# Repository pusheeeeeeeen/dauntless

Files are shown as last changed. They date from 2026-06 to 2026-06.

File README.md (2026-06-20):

# LiHv battery charger V1+V2
LiHv battery charger capable of charging LiHv batteries up to 4.35v, custom 3d designed case for 3d printing and an on-off switch. V1 is the simplest module, just to be available for cheaper and easier production of 4.35v LiHv chargers. V2 is equipped with a buzzer, OLED display, and XIAO RP2040 module to track battery percentage, and to alert the user when the battery is done charging. 

## V1: Mr. Barebones
### 3D rendering
Screenshot 2026-06-17 at 2 48 51 PM

### Schematic
Screenshot 2026-06-15 at 2 58 24 PM

### PCB Layout
Screenshot 2026-06-19 at 8 40 17 PM

## V2: The Upgrade
### 3D rendering
Screenshot 2026-06-19 at 8 35 19 PM

### Schematic
Screenshot 2026-06-18 at 3 53 26 PM

### PCB Layout
Screenshot 2026-06-19 at 8 37 02 PM

## BOM:
https://docs.google.com/spreadsheets/d/1y4eYakeZhQ_Du6QSC2gYvQQuMS255J4ouP4txh3QHf0/edit?gid=0#gid=0

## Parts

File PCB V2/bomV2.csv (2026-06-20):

Reference | Value | Footprint | Datasheet | Qty | DNP | Exclude from BOM | Exclude from Board
BZ1 | Buzzer | Buzzer_Beeper:Buzzer_D14mm_H7mm_P10mm | ~ | 1
C2,C3 | 10uF | Capacitor_THT:CP_Radial_D5.0mm_P2.50mm | ~ | 2
D1,D2 | LED | LED_SMD:LED_0805_2012Metric_Pad1.15x1.40mm_HandSolder | ~ | 2
J1 | "OLED Display" | Connector_PinSocket_2.54mm:PinSocket_1x04_P2.54mm_Vertical | ~ | 1
J2,J3 | Conn_01x01 | Connector_PinSocket_2.54mm:PinSocket_1x01_P2.54mm_Vertical | ~ | 2
R3 | 2.2k | Resistor_SMD:R_0805_2012Metric_Pad1.20x1.40mm_HandSolder | ~ | 1
R4,R5 | 1k | Resistor_SMD:R_0805_2012Metric_Pad1.20x1.40mm_HandSolder | ~ | 2
R6,R8 | 0.2 | Resistor_SMD:R_0805_2012Metric_Pad1.20x1.40mm_HandSolder | ~ | 2
R7 | 10k | Resistor_SMD:R_0805_2012Metric_Pad1.20x1.40mm_HandSolder | ~ | 1
SW1 | SW_SPST | Button_Switch_THT:SW_Slide_SPDT_Straight_CK_OS102011MS2Q | ~ | 1
U1 | TP4056X-435-ESOP8 | Package_SO:SOIC-8-1EP_3.9x4.9mm_P1.27mm_EP2.62x3.51mm_ThermalVias | https://www.lcsc.com/datasheet/lcsc_datasheet_2410121619_TOPPOWER-Nanjing-Extension-Microelectronics-TP4056-42-ESOP8_C16581.pdf | 1
U2 | XIAO-RP2040-SMD | SeeedStudioLibrary:XIAO-RP2040-SMD |  | 1

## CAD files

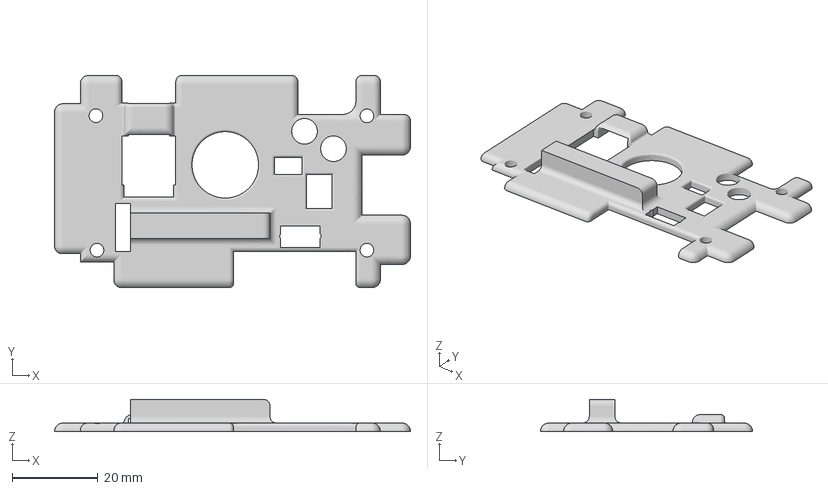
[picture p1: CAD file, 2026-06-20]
PCB V2/LiHvbatterychargerV2enclosuretopcover.3mf
83.0 x 49.5 x 7.51 mm

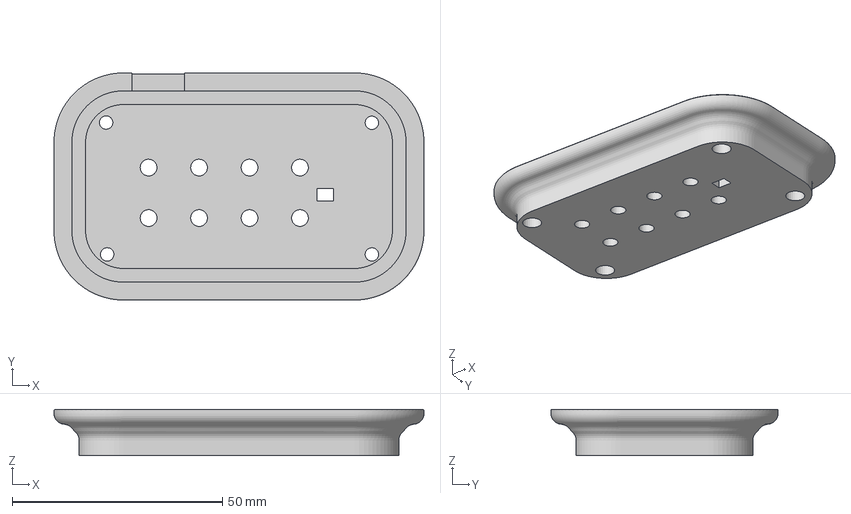
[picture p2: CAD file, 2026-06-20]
PCB V2/LiHvbatterychargerV2enclosurebottom.3mf
88.0 x 54.0 x 11.0 mm

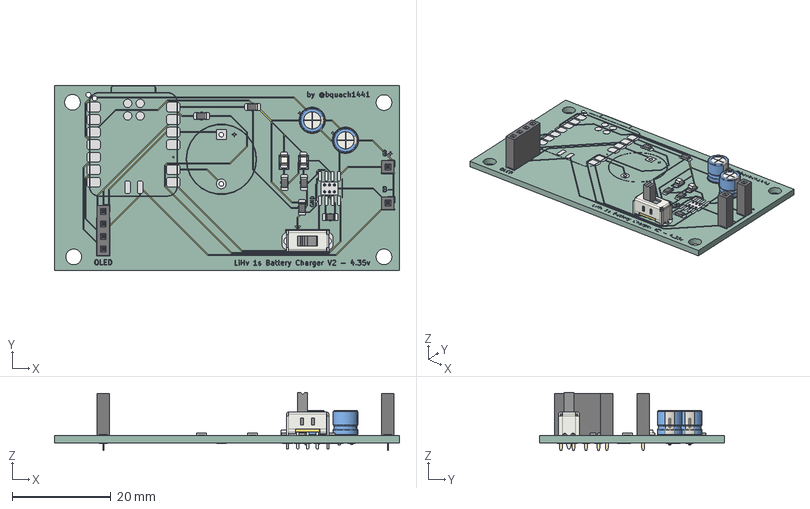
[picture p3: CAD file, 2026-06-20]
PCB V2/LiHvbatterychargerv3.step
70.0 x 37.5 x 11.8 mm
PinSocket_1x01_P2.54mm_Vertical x 2
PinSocket_1x04_P2.54mm_Vertical
CP_Radial_D5.0mm_P2.50mm x 2
R_0805_2012Metric x 6
LED_0805_2012Metric x 2
SW_Slide_SPDT_Straight_CK_OS102011MS2Q
LiHvbatterychargerv3_copper
LiHvbatterychargerv3_pad
LiHvbatterychargerv3_silkscreen
LiHvbatterychargerv3_PCB

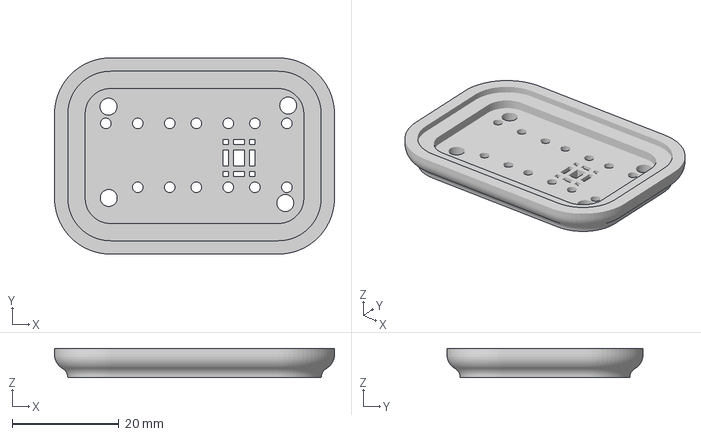
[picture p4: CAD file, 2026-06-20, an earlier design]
PCB V1/LiHvbatterychargerV1bottomenclosure.3mf
52.6 x 36.8 x 5.50 mm

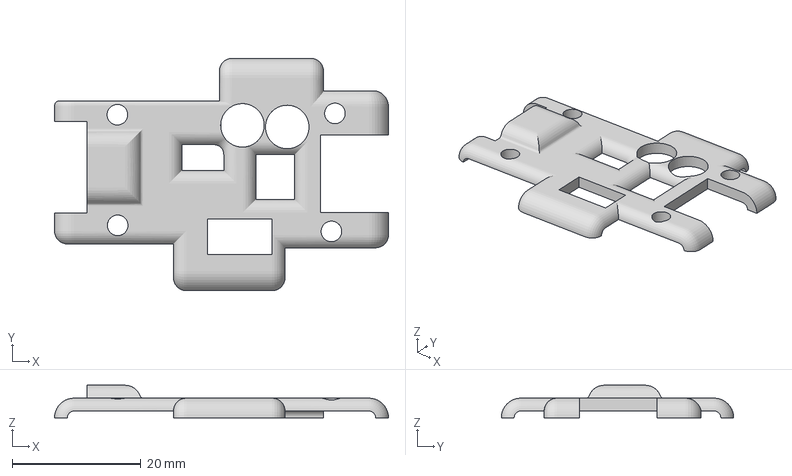
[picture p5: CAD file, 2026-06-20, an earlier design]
PCB V1/LiHvbatterychargerV1enclosuretopcover.3mf
51.8 x 36.1 x 5.06 mm

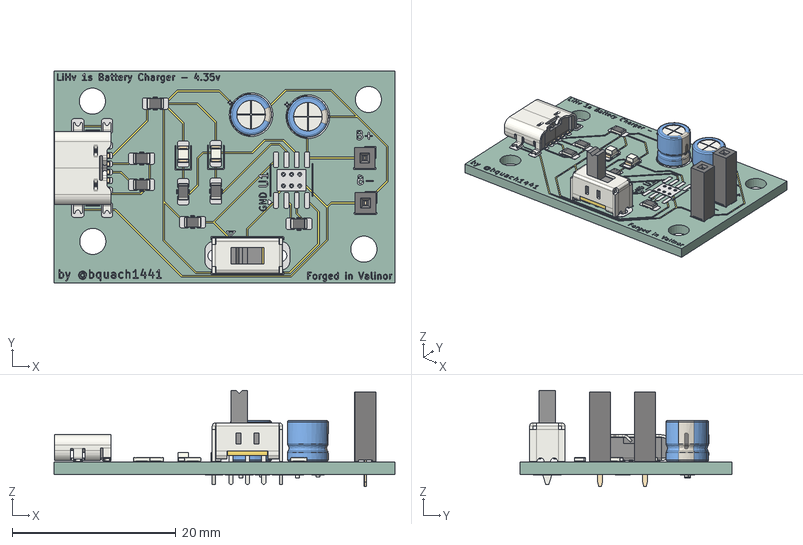
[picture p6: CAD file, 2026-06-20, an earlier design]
PCB V1/LiHvbatterychargerv2.step
41.7 x 25.9 x 11.8 mm
R_0805_2012Metric x 7
CP_Radial_D5.0mm_P2.50mm x 2
LED_0805_2012Metric x 2
PinSocket_1x01_P2.54mm_Vertical x 2
USB_C_Receptacle_GCT_USB4135-GF-A_6P_TopMnt_Horizontal
SW_Slide_SPDT_Straight_CK_OS102011MS2Q
LiHvbatterychargerv2_copper
LiHvbatterychargerv2_pad
LiHvbatterychargerv2_silkscreen
LiHvbatterychargerv2_PCB

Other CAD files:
PCB V1/LiHvbatterychargerv2enclosure.f3z

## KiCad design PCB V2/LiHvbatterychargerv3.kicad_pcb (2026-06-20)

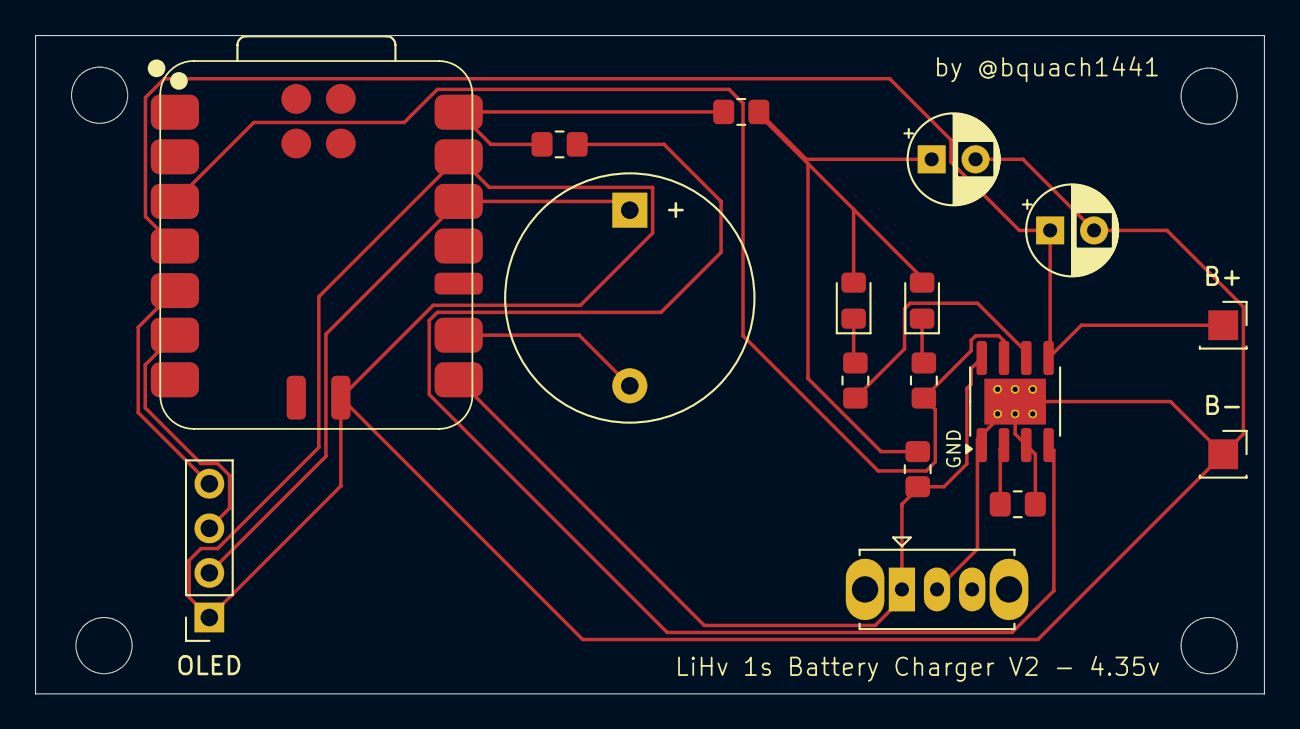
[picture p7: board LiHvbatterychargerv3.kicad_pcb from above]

Board: 2 copper layers, 70.0 x 37.5 mm, 17 parts (0 on the bottom side), 15 nets.

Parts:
B+: Conn_01x01; PinSocket_1x01_P2.54mm_Vertical
B-: Conn_01x01; PinSocket_1x01_P2.54mm_Vertical
BZ1: Buzzer; Buzzer_D14mm_H7mm_P10mm
C2, C3: 10uF; CP_Radial_D5.0mm_P2.50mm
D1, D2: LED; LED_0805_2012Metric_Pad1.15x1.40mm_HandSolder
OLED: "OLED Display"; PinSocket_1x04_P2.54mm_Vertical
R3: 2.2k; R_0805_2012Metric_Pad1.20x1.40mm_HandSolder
R4, R5: 1k; R_0805_2012Metric_Pad1.20x1.40mm_HandSolder
R6, R8: 0.2; R_0805_2012Metric_Pad1.20x1.40mm_HandSolder
R7: 10k; R_0805_2012Metric_Pad1.20x1.40mm_HandSolder
SW1: SW_SPST; SW_Slide_SPDT_Straight_CK_OS102011MS2Q
U1: TP4056X-42-ESOP8; SOIC-8-1EP_3.9x4.9mm_P1.27mm_EP2.62x3.51mm_ThermalVias
U2: XIAO-RP2040-SMD

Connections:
GND: B-.1, C2.2, C3.2, OLED.1, R3.1, SW1.2 (B), U1.1 (TEMP), U1.3 (GND), U1.9 (EPAD), U2.13 (GND), U2.33 (GND)
unnamed: BZ1.1 (+), OLED.2, U2.12 (3V3)
unnamed: BZ1.2 (-), U2.9 (P2_D8_SCK)
unnamed: C2.1, D1.2 (A), D2.2 (A), R6.1, R7.2
unnamed: D1.1 (K), R5.2
unnamed: D2.1 (K), R4.2
unnamed: OLED.3, U2.6 (P7_SCL_D5)
unnamed: OLED.4, U2.5 (P6_SDA_D4)
unnamed: B+.1, C3.1, U1.5 (BAT), U2.4 (P29_A3_D3)
unnamed: R7.1, SW1.1 (A), U1.8 (CE), U2.8 (P1_D7_RX)
unnamed: R3.2, U1.2 (PROG)
unnamed: R8.1, U1.4 (V_{CC})
unnamed: R5.1, U1.7 (~CHRG), U2.3 (P28_A2_D2)
unnamed: R4.1, U1.6 (~STDBY)
unnamed: R6.2, R8.2, U2.14 (VBUS)

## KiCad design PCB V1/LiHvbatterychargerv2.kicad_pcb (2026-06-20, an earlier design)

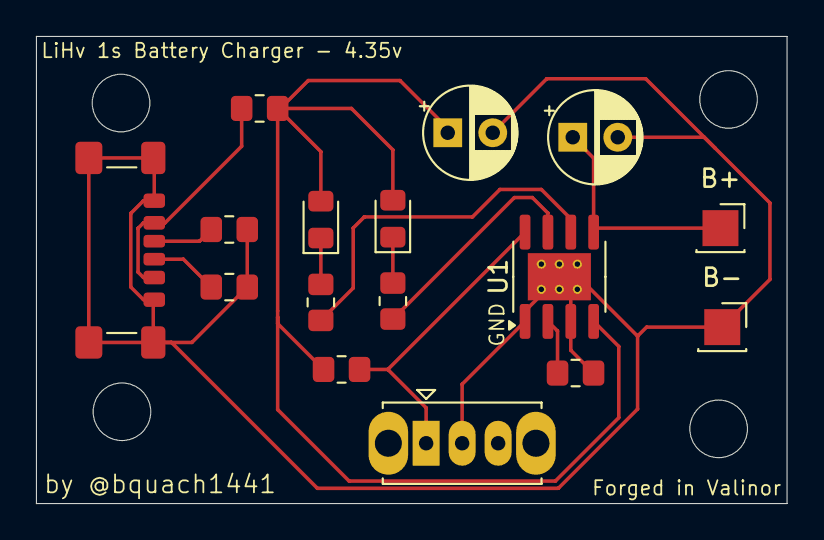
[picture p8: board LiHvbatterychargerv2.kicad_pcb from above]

Board: 2 copper layers, 41.7 x 25.9 mm, 16 parts (0 on the bottom side), 12 nets.

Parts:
B+: Conn_01x01; PinSocket_1x01_P2.54mm_Vertical
B-: Conn_01x01; PinSocket_1x01_P2.54mm_Vertical
C2, C3: 10uF; CP_Radial_D5.0mm_P2.50mm
D1, D2: LED; LED_0805_2012Metric_Pad1.15x1.40mm_HandSolder
J1: USB_C_Receptacle_PowerOnly_6P; USB_C_Receptacle_GCT_USB4135-GF-A_6P_TopMnt_Horizontal
R1, R2: 5.1k; R_0805_2012Metric_Pad1.20x1.40mm_HandSolder
R3: 2.2k; R_0805_2012Metric_Pad1.20x1.40mm_HandSolder
R4, R5: 1k; R_0805_2012Metric_Pad1.20x1.40mm_HandSolder
R6: 0.2; R_0805_2012Metric_Pad1.20x1.40mm_HandSolder
R7: 10k; R_0805_2012Metric_Pad1.20x1.40mm_HandSolder
SW1: SW_SPST; SW_Slide_SPDT_Straight_CK_OS102011MS2Q
U1: TP4056X-42-ESOP8; SOIC-8-1EP_3.9x4.9mm_P1.27mm_EP2.62x3.51mm_ThermalVias

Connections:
GND: B-.1, C2.2, C3.2, J1.A12 (GND), J1.B12 (GND), J1.S1 (SHIELD), R1.2, R2.2, R3.1, SW1.2 (B), U1.1 (TEMP), U1.3 (GND), U1.9 (EPAD)
unnamed: C2.1, D1.2 (A), D2.2 (A), R6.1, R7.2, U1.4 (V_{CC})
unnamed: D1.1 (K), R5.2
unnamed: D2.1 (K), R4.2
unnamed: J1.A5 (CC1), R1.1
unnamed: J1.B5 (CC2), R2.1
unnamed: J1.A9 (VBUS), J1.B9 (VBUS), R6.2
unnamed: B+.1, C3.1, U1.5 (BAT)
unnamed: R7.1, SW1.1 (A), U1.8 (CE)
unnamed: R3.2, U1.2 (PROG)
unnamed: R5.1, U1.7 (~CHRG)
unnamed: R4.1, U1.6 (~STDBY)

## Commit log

2026-06-20 Added PCBV1 files
    [LiHvbatterychargerv2.kicad_pcb, LiHvbatterychargerv2.kicad_sch, LiHvbatterychargerv2.step]
2026-06-20 Create PCB V2
2026-06-20 Added PCB V2 files
    [LiHvbatterychargerv3.kicad_pcb, LiHvbatterychargerv3.kicad_sch, LiHvbatterychargerv3.step]
2026-06-20 Added enclosure 3mf files for V1
    [LiHvbatterychargerV1bottomenclosure.3mf, LiHvbatterychargerV1enclosuretopcover.3mf]
